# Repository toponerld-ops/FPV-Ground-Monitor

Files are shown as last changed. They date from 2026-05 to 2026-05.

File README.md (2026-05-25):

# FPV Ground Monitor 

A custom-built open-source FPV ground station monitor built on the **Radxa Zero 3W** SBC, featuring a custom uHAT PCB for power management, a RTL8812AU WiFi dongle for receiving **OpenIPC** video streams from drones via **WFB-ng**.

Designed to pair with the **MAR Racing Drone** -- a custom 75mm FPV tiny whoop with a fully custom 8-in-1 AIO flight controller (also Hackclub Fallout funded), this monitor closes the loop on a fully open-source, end-to-end FPV video system.

---

## What is it?

A portable, battery-powered FPV video ground station that:

- Receives HD video from an OpenIPC-based drone over 5.8GHz via WFB-ng
- Displays live feed on a 7" HDMI screen via PixelPilot OS on the Radxa Zero 3W
- Powers everything from a 3S 11.1V li-ion battery via a custom uHAT buck converter PCB
- Features 3x WS2812B RGB LEDs for link/recording/battery status
- Has 3 navigation buttons + 1 power button for PixelPilot UI control
- Has an SSD1306 OLED for IP/battery/link status display
- Exposes a UART debug header for development

---

## Why did I make it?

I'm building the MAR Racing Drone -- a fully custom FPV drone with a custom AIO flight controller and an OpenIPC video system (SSC338Q + IMX415). To test and use the video link, I needed a ground station that:

1. Works with OpenIPC/WFB-ng (no DJI goggles)
2. Is portable and battery powered
3. Is fully open source and hackable
4. Is cheap enough to actually build

Commercial alternatives (DJI Goggles, Walksnail) cost $300-600 and lock you into a proprietary ecosystem. This monitor costs under ₹15,000 (~$180) and works with any OpenIPC drone.

---

## How do you use it?

1. Flash PixelPilot OS onto the 64GB microSD card
2. Plug the RTL8812AU dongle into the USB-A port on the uHAT
3. Connect the 3S battery to the XT30 connector on the uHAT
4. Power on via the power button
5. Connect your 7" HDMI display
6. Power on your OpenIPC drone
7. PixelPilot auto-connects via WFB-ng and displays the video feed

---

## Hardware

### BOM

| Component | Part | Source | Qty | Price (INR) |
|---|---|---|---|---|
| SBC | Radxa Zero 3W 2GB | Hubtronics | 1 | ₹6,900 |
| WiFi Module | RTL8812AU USB dongle | Robokits | 1 | ₹975 |
| Display | Waveshare 7" HDMI Capacitive | Robu | 1 | ₹2,500 |
| Battery | 3S 11.1V 2000mAh Li-ion | Robu | 1 | ₹900 |
| MicroSD | SanDisk 64GB A1 | Robu | 1 | ₹550 |
| uHAT PCB | Custom (this repo) | JLCPCB | 1 | ~₹800 |
| Buck Converter | MP2307DN-LF-Z | LCSC C18921 | 1 | - |
| RGB LEDs | WS2812B-V5 | LCSC C691873 | 3 | - |
| Buttons | TS-1187A-B-A-B | LCSC C318884 | 4 | - |
| OLED | SSD1306 128x64 I2C module | AliExpress | 1 | ₹150 |
| 40-pin Header | IDC-SMD_40P-P2.54 | LCSC C9900016611 | 1 | - |
| USB-A Socket | USB3.0VerticalTypeA | LCSC C9900010398 | 1 | - |
| Battery Connector | KF301-2P | LCSC C9900016950 | 1 | - |

Full BOM with LCSC part numbers in `BOM(1).csv`

---

## PCB -- uHAT

The custom uHAT PCB sits on top of the Radxa Zero 3W's 40-pin GPIO header and provides:

- **Power**: 11.1V 3S battery → MP2307 buck converter → 5V rail for Zero 3W + display
- **USB**: Routes USB 2.0 from GPIO header pins 27/28 to USB-A socket for WiFi dongle
- **Interface**: 4x tactile buttons, 3x WS2812B RGB LEDs, SSD1306 OLED connector
- **Debug**: UART header (TX/RX/GND) for serial debug access
- **Protection**: Polyfuse on battery input, 100nF decoupling on all power rails

### PCB Specs
- Size: 65 x 30mm
- Layers: 2
- Manufacturer: JLCPCB standard

---
### Firmware
The FPV Ground Monitor runs PixelPilot OS on the Radxa Zero 3W SBC. PixelPilot is an open-source ground station OS built specifically for OpenIPC FPV systems using WFB-ng.
No custom firmware is required -- PixelPilot handles video decoding, display output, and WiFi link management out of the box.

Setup Instructions
1. Flash PixelPilot OS

Download the latest PixelPilot OS image for Radxa Zero 3W from:
https://github.com/OpenIPC/PixelPilot/releases
Flash to a 64GB microSD card using Balena Etcher
Insert microSD into the Radxa Zero 3W

2. Hardware Assembly

Plug the RTL8812AU WiFi dongle into the USB-A port on the uHAT
Connect the 3S 11.1V battery to the XT30 connector on the uHAT
Connect the 7" HDMI display via micro HDMI to HDMI cable
Stack the uHAT onto the Radxa Zero 3W 40-pin GPIO header

3. Power On

Press the power button on the uHAT
PixelPilot OS boots automatically
The RTL8812AU driver is included in PixelPilot OS -- no manual setup needed

4. Connecting to Drone

Power on your OpenIPC drone with WFB-ng configured
PixelPilot automatically scans for WFB-ng streams on 5.8GHz
Video feed appears on the HDMI display within 5-10 seconds

WFB-ng Configuration
For the drone side (MAR Racing Drone AIO FC with SSC338Q + IMX415):

WFB-ng frequency: 5745 MHz (default)
TX power: set in /etc/wfb.conf on the drone
Recommended MCS index: 1 (balance of range and bitrate)
Encoding: H.265 for best quality at low bitrate

For full WFB-ng configuration guide:
https://github.com/svpcom/wfb-ng/wiki

GPIO Button and LED Control (Optional)
The uHAT exposes 4 buttons and 3 WS2812B RGB LEDs via the Radxa Zero 3W GPIO. A Python script can be run on boot to handle these.
Dependencies:
pip install RPi.GPIO rpi-ws281x
Button GPIO pins (BCM numbering):

BTN1: GPIO17 (Pin 11)
BTN2: GPIO27 (Pin 13)
BTN3: GPIO22 (Pin 15)
PWR BTN: GPIO23 (Pin 16)

LED data pin:

GPIO_LED1: GPIO24 (Pin 18) -- WS2812B data in

OLED (SSD1306 I2C):

SDA: GPIO2 (Pin 3)
SCL: GPIO3 (Pin 5)

Sample script for LED status and OLED display coming soon.

References

PixelPilot: https://github.com/OpenIPC/PixelPilot

WFB-ng: https://github.com/svpcom/wfb-ng

OpenIPC: https://openipc.org

Radxa Zero 3W: https://radxa.com/products/zeros/zero3w

---

## Zine Page

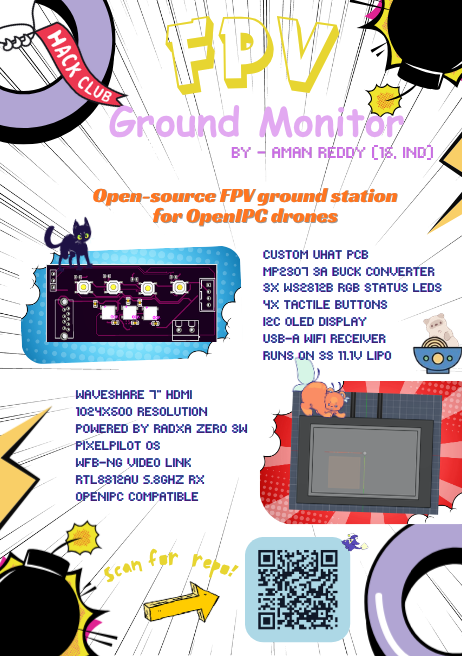
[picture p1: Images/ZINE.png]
Zine Page


---

## Top View

Top View

## Side view

Side View

## Bottom view 

Bottom View

## PCB Top view

PCB Top view

## PCB Bottom view

PCB Bottom view

---

**Made by Aman | Age 16 | Hyderabad, India**

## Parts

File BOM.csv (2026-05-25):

No. | Quantity | Component | Designator | Footprint | LCSC Part | Manufacturer | Price (INR) | Category | Notes | Link
1 | 14 | 100nF Capacitor 0603 | C1-C14 | C0603 | C14663 |  | 2 | PCB Component | Hand Solder | https://www.lcsc.com/product-detail/C14663.html
2 | 1 | 4.7uH Inductor 0603 | L1 | L0603 | C1034 |  | 4 | PCB Component | Hand Solder | https://www.lcsc.com/product-detail/C1034.html
3 | 1 | 100K Resistor 0603 | R1 | R0603 | C25803 |  | 1 | PCB Component | Hand Solder | https://www.lcsc.com/product-detail/C25803.html
4 | 1 | 25.5K Resistor 0603 | R2 | R0603 | C22920 |  | 1 | PCB Component | Hand Solder | https://www.lcsc.com/product-detail/C22920.html
5 | 4 | 10K Resistor 0603 | R3-R6 | R0603 | C25804 |  | 2 | PCB Component | Hand Solder | https://www.lcsc.com/product-detail/C25804.html
6 | 1 | SS34 Schottky Diode | D1 | SOD-123 | C108862 |  | 2 | PCB Component | Hand Solder | https://www.lcsc.com/product-detail/C108862.html
7 | 4 | TS-1187A-B-A-B Tactile Switch | SW1-SW4 | SW-SMD-4P | C318884 | XKB Connection | 2 | PCB Component | Hand Solder | https://www.lcsc.com/product-detail/C318884.html
8 | 1 | MP2307DN-LF-Z Buck Converter | U1 | SOIC-8N-EP | C18921 | MPS | 308 | PCB Component | Reflow Solder | https://www.lcsc.com/product-detail/C18921.html
9 | 3 | WS2812B-V5/W RGB LED | U5-U7 | LED-SMD-5x5 | C2874885 |  | 12 | PCB Component | Reflow Solder | https://www.lcsc.com/product-detail/C2874885.html
10 | 1 | Fuse F1206 | F1 | F1206 | C9900021114 |  | 5 | PCB Component | Hand Solder | https://www.lcsc.com/product-detail/C9900021114.html
11 | 1 | KF301-2P Screw Terminal | P1 | CONN-TH | C9900016950 |  | 5 | PCB Component | Hand Solder | https://www.lcsc.com/product-detail/C9900016950.html
12 | 1 | 40P 2.54mm GPIO Header | U2 | HDR-SMD-40P | C9900016611 |  | 15 | PCB Component | Hand Solder | https://www.lcsc.com/product-detail/C9900016611.html
13 | 1 | USB 3.0 Type-A Vertical Socket | U3 | USB-A-TH | C9900010398 |  | 5 | PCB Component | Hand Solder | https://www.lcsc.com/product-detail/C9900010398.html
14 | 1 | 1X4P Pin Header 2.54mm | U4 | CONN-TH-4P | C9900022166 |  | 3 | PCB Component | Hand Solder | https://www.lcsc.com/product-detail/C9900022166.html
15 | 1 | 1X3P Pin Header 2.54mm | U8 | HDR-TH-3P | C9900016709 |  | 3 | PCB Component | Hand Solder | https://www.lcsc.com/product-detail/C9900016709.html
16 | 1 | PCB Fabrication + Stencil (JLCPCB - 5 boards) |  |  |  | JLCPCB | 2060 | PCB |  | https://jlcpcb.com
17 | 1 | Radxa Zero 3W 2GB SBC |  |  |  | Radxa | 6900 | Electronics |  | https://radxa.com/products/zeros/zero3w
18 | 1 | RTL8812AU USB WiFi Dongle |  |  |  | Generic | 975 | Electronics |  | https://robu.in/product/rtl8812au-600mbps-dual-band-wireless-usb-wifi-adapter/
19 | 1 | Waveshare 7inch HDMI LCD 1024x600 |  |  |  | Waveshare | 2500 | Electronics |  | https://robu.in/product/waveshare-7inch-hdmi-lcd/
20 | 1 | 3S 11.1V 2000mAh Li-ion Battery |  |  |  | Generic | 900 | Electronics |  | https://robu.in/product/11-1v-2000mah-3c-3s1p-li-ion-battery-pack/
21 | 1 | SanDisk 64GB MicroSD A1 |  |  |  | SanDisk | 550 | Electronics |  | https://robu.in/product/sandisk-64gb-ultra-microsdxc-uhs-i-card/
22 | 1 | SSD1306 128x64 OLED Module |  |  |  | Generic | 150 | Electronics |  | https://robu.in/product/0-96-inch-i2c-iic-serial-128x64-oled-lcd-led-display-module/
23 | 1 | Micro HDMI to HDMI Cable |  |  |  | Generic | 200 | Electronics |  | https://robu.in
24 | 1 | YIHUA 926 Soldering Station |  |  |  | YIHUA | 1440 | Tool |  | https://robu.in/product/yihua-926-upgrade-version-soldering-iron-station/
25 | 1 | ELBME G3061 PD65W Hot Plate |  |  |  | ELBME | 4989 | Tool |  | https://www.amazon.in/dp/B0F3TP5X62
26 | 1 | Noise 65W GaN Charger + USB-C Cable |  |  |  | Noise | 2399 | Tool |  | https://www.amazon.in/dp/B0F9F2RCR4
27 | 1 | boAt USB-C to USB-C Cable |  |  |  | boAt | 349 | Tool |  | https://www.amazon.in/dp/B0FMRNR4LY
28 | 1 | SMD Solder Paste (63/37) |  |  |  | Generic | 300 | Tool |  | https://robu.in
TOTAL |  |  |  |  |  |  | 23082

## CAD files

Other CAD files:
CAD/FPV_GROUND_STATION_CAD_CASE (Assembly).step
CAD/FPV_GROUND_STATION_CAD_CASE.step
CAD/FPV_GROUND_STATION_CAD_CASE.f3d

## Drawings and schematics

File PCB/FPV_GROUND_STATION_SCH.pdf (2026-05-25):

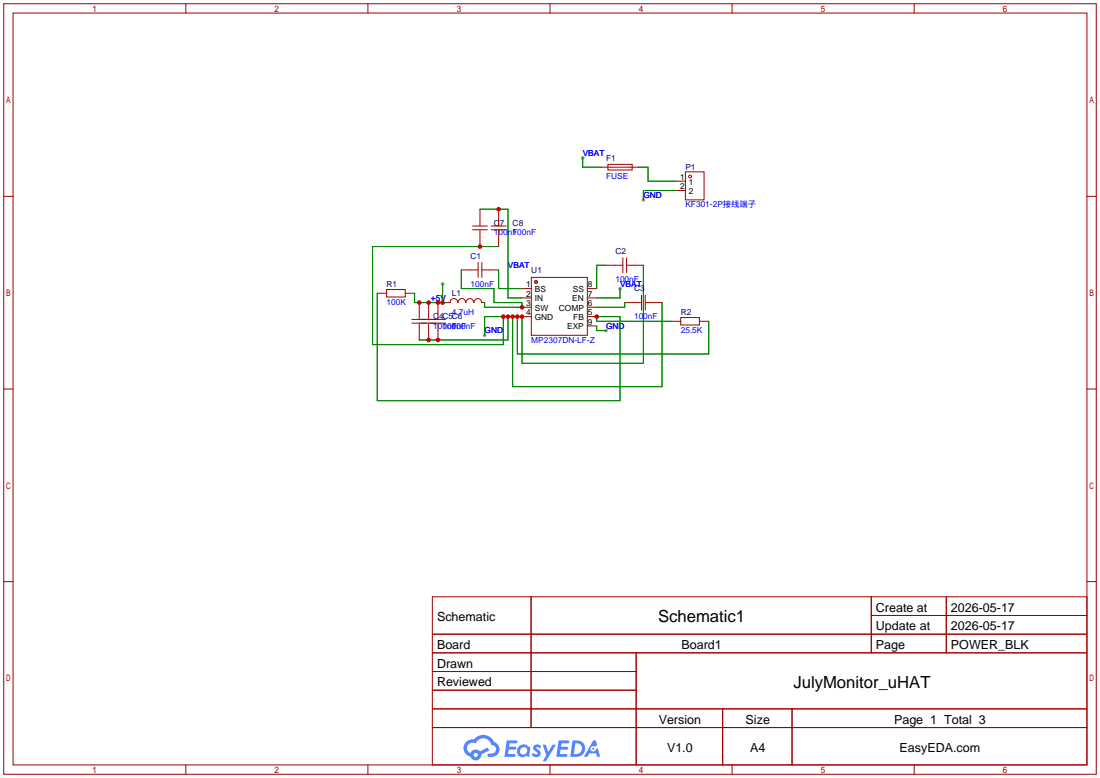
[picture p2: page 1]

Schematic | Schematic1 | Create at | 2026-05-17

Update at | 2026-05-17

Board | Board1 | Page | POWER_BLK
Drawn | | JulyMonitor_uHAT
Reviewed

Version | Size | Page 1 Total 3
V1.0 | A4 | EasyEDA.com

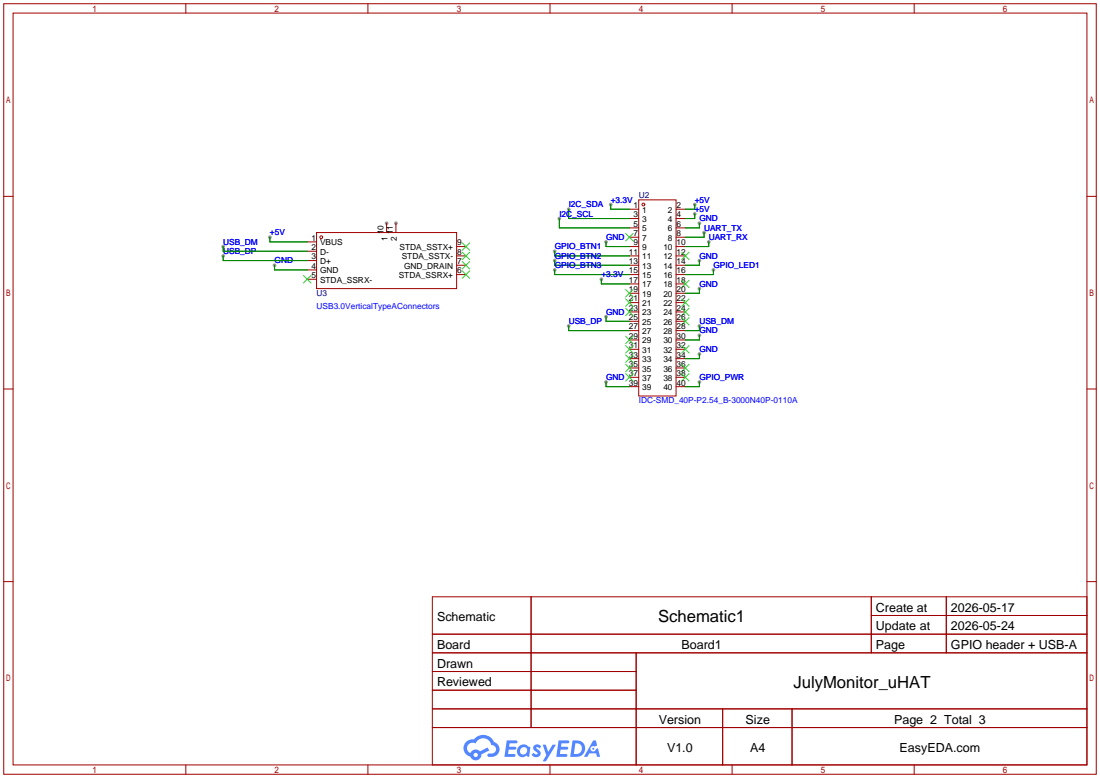
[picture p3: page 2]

Schematic | Schematic1 | Create at | 2026-05-17

Update at | 2026-05-24

Board | Board1 | Page | GPIO header + USB-A
Drawn | | JulyMonitor_uHAT
Reviewed

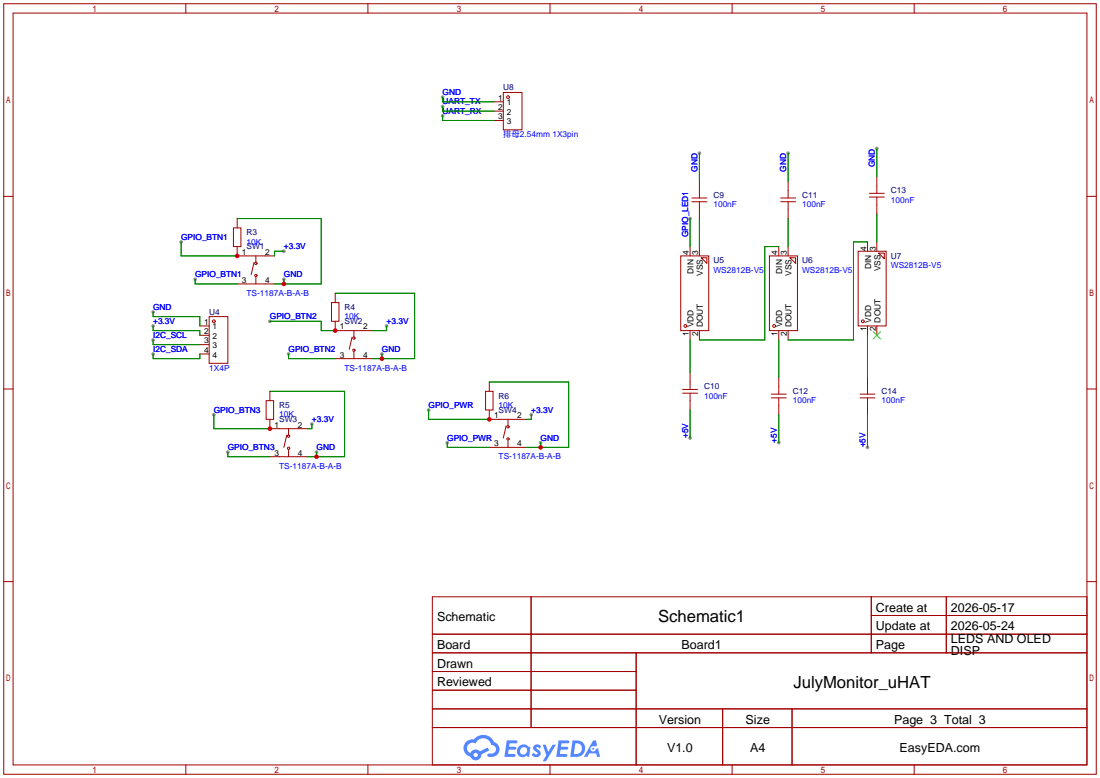
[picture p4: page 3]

Schematic | Schematic1 | Create at | 2026-05-17
Board | Board1 | Page | LEDS AND OLED
Drawn | | JulyMonitor_uHAT
Reviewed

Update at | 2026-05-24

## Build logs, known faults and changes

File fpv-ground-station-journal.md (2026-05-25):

# FPV GROUND STATION — Journal Export

- Exported at: 2026-05-25T13:59:48Z
- Project ID: 3503
- Entries: 17

## Entry 1
- ID: 7588
- Author: toponerld
- Created At: 2026-05-17T11:36:19Z

### Content

Started the uHAT schematic for the July FPV Monitor in EasyEDA Pro. The uHAT sits on top of the Radxa Zero 3W's 40-pin GPIO header and handles all the power management for the monitor.
Today I completed the power input block. The battery connects through a KF301-2P screw terminal, goes through a fuse for protection, and into an MP2307DN buck converter that steps the 11.1V 3S li ion battery down to a clean 5V rail. Added input and output filtering caps, bootstrap cap, soft start cap, freewheeling SS34 Schottky diode, and a resistor divider on the FB pin set for 5V output.
Next up: 40-pin GPIO header for the Radxa Zero 3W and the USB-A socket for the RTL8812AU WiFi dongle.
Screenshot 2026-05-17 165958.png

### Recording Links

- https://public.lapse-hackclub.link/timelapses/X917GN-vhyAR/timelapse-X917GN-vhyAR.mp4

## Entry 2
- ID: 7595
- Author: toponerld
- Created At: 2026-05-17T12:15:31Z

### Content

Added the Radxa Zero 3W 40-pin GPIO header (IDC-SMD_40P-P2.54) and mapped all used pins 5V power input, GND, 3.3V, I2C for OLED, UART for debug, and 6 GPIO pins for buttons and LEDs. Remaining pins got no-connect markers.
Added a USB 3.0 Type-A vertical socket for the RTL8812AU WiFi dongle. Connected VBUS to +5V, GND, and routed D+ and D- to pins 27 and 28 on the GPIO header. SS pins no-connected since Zero 3W GPIO only exposes USB 2.0.
Next: buttons, LEDs and OLED 
Screenshot 2026-05-17 174520.png

### Recording Links

- https://public.lapse-hackclub.link/timelapses/cNxJUGiLqJAZ/timelapse-cNxJUGiLqJAZ.mp4

## Entry 3
- ID: 7601
- Author: toponerld
- Created At: 2026-05-17T12:54:14Z

### Content

Added the interface components on page 3. Placed a 4-pin header for the SSD1306 OLED module connected to I2C (SCL/SDA) with 3.3V and GND.
Added 4 tactile buttons (TS-1187A-B-A-B) -- 3 for UI navigation and 1 dedicated power button. Each has a 10K pulldown resistor to ensure clean LOW reads when unpressed.
For LEDs went with 3x WS2812B-V5 addressable RGB LEDs instead of plain single color -- all controlled from a single GPIO pin via data chaining. Each LED has a dedicated role: link status, recording status, and battery level. Added 100nF decoupling caps on each.
DRC passed with 0 errors on all 3 pages.
Next: PCB layout.
Screenshot 2026-05-17 182300.png

### Recording Links

- https://public.lapse-hackclub.link/timelapses/5m16LrcEGvKj/timelapse-5m16LrcEGvKj.mp4

## Entry 4
- ID: 7637
- Author: toponerld
- Created At: 2026-05-17T16:38:28Z

### Content

Finished the schematic and started tracing the pcb looks like i have a lot to learn in tracing will take help
Screenshot 2026-05-17 220814.png

### Recording Links

- https://public.lapse-hackclub.link/timelapses/uewIPvZDGqOo/timelapse-uewIPvZDGqOo.mp4

## Entry 5
- ID: 8815
- Author: toponerld
- Created At: 2026-05-24T07:38:45Z

### Content

soooooo i forgot to save and i lost my traced pcb so i made it again and have no errors in drc and have a few errors in dfm so have to fix those 
Screenshot 2026-05-24 130830.png

### Recording Links

- https://public.lapse-hackclub.link/timelapses/6hfgF1i-I5Ng/timelapse-6hfgF1i-I5Ng.mp4
- https://public.lapse-hackclub.link/timelapses/8OSZpo_ioEFw/timelapse-8OSZpo_ioEFw.mp4

## Entry 6
- ID: 8825
- Author: toponerld
- Created At: 2026-05-24T09:02:11Z

### Content

okayy so finished everything only silkscreen errors in dfm so the pcb is done!!!! now its time to build it heheheh.
Screenshot 2026-05-24 142334.png

### Recording Links

- https://public.lapse-hackclub.link/timelapses/la_aP5qNe96_/timelapse-la_aP5qNe96_.mp4

## Entry 7
- ID: 8861
- Author: toponerld
- Created At: 2026-05-24T13:12:09Z

### Content

Im making the outer case for the fpv ground station i paused a lot in between cause i was taking measurements from the PCB i made 
Screenshot 2026-05-24 183717.png
Screenshot 2026-05-24 184144.png

### Recording Links

- https://public.lapse-hackclub.link/timelapses/Htptf2LEvjc1/timelapse-Htptf2LEvjc1.mp4

## Entry 8
- ID: 8873
- Author: toponerld
- Created At: 2026-05-24T14:32:58Z

### Content

major changes looks like i messed up the button, led and the connector holes and then i added the step files of the components then assembled them now i have to make the holes for them then it will be done heheh.
Screenshot 2026-05-24 200159.png
Screenshot 2026-05-24 200247.png

### Recording Links

- https://public.lapse-hackclub.link/timelapses/Tq5StU_N6Mgt/timelapse-Tq5StU_N6Mgt.mp4

## Entry 9
- ID: 8889
- Author: toponerld
- Created At: 2026-05-24T15:41:06Z

### Content

uhhhhhhhhhhhh i cant seem to find how to make holes to the case according to the pcb i made on the case!!
Screenshot 2026-05-24 211056.png

### Recording Links

- https://public.lapse-hackclub.link/timelapses/W3pzDga-OvNf/timelapse-W3pzDga-OvNf.mp4

## Entry 10
- ID: 8916
- Author: toponerld
- Created At: 2026-05-24T16:59:24Z

### Content

sooooo i finished the holes for the pcb buttons and ledsss finnally i can sleep i grinded alott today gettin closer to the goal imma give my very best so that i can go to sz!!
Screenshot 2026-05-24 222402.png

### Recording Links

- https://public.lapse-hackclub.link/timelapses/qM8SKp4SDo91/timelapse-qM8SKp4SDo91.mp4

## Entry 11
- ID: 9014
- Author: toponerld
- Created At: 2026-05-25T02:22:44Z

### Content

made the antennas or the case and added support brackets and mounting holes for the radax pi zero w3 
Screenshot 2026-05-25 075218.png

### Recording Links

- https://public.lapse-hackclub.link/timelapses/9Zzg_7UHkDmC/timelapse-9Zzg_7UHkDmC.mp4

## Entry 12
- ID: 9023
- Author: toponerld
- Created At: 2026-05-25T03:32:46Z

### Content

soo i finished everything now making the repo so i made the BOM and uploaded all the files then set up lfs cause the files were too big and made the repo clean. i have to finalize the BOM and submit!!
Screenshot 2026-05-25 083422.png

### Recording Links

- https://public.lapse-hackclub.link/timelapses/kwZ2xxx-BgNz/timelapse-kwZ2xxx-BgNz.mp4

## Entry 13
- ID: 9040
- Author: toponerld
- Created At: 2026-05-25T04:48:32Z

### Content

im havin problems with jlcpcb looks llike sm of my components are out of stock so i got fedup and started making the zine page will complete soon, wish me luck!
Screenshot 2026-05-25 101821.png

### Recording Links

- https://public.lapse-hackclub.link/timelapses/U2qUrNBQRouZ/timelapse-U2qUrNBQRouZ.mp4

## Entry 14
- ID: 9063
- Author: toponerld
- Created At: 2026-05-25T08:35:56Z

### Content

Made the zine pagee put a lot of effort into itt and a bit of advice from krishh!! it looks good hope it will get printed
FPV (1).png

### Recording Links

- https://public.lapse-hackclub.link/timelapses/IqYz93zXrst4/timelapse-IqYz93zXrst4.mp4

## Entry 15
- ID: 9073
- Author: toponerld
- Created At: 2026-05-25T09:42:43Z

### Content

I completed the zine before but missed a couple of things like the name age country a brief discription so ive added those now


### Recording Links

- https://public.lapse-hackclub.link/timelapses/jWElGVDbj_cF/timelapse-jWElGVDbj_cF.mp4

## Entry 16
- ID: 9086
- Author: toponerld
- Created At: 2026-05-25T10:49:25Z

### Content

I removed all the components from the top side of the pcb and place them all on the bottom side to cut costs, it was a lot of workkk
Screenshot 2026-05-25 161907.png

### Recording Links

- https://public.lapse-hackclub.link/timelapses/EmE-8jUR9670/timelapse-EmE-8jUR9670.mp4

## Entry 17
- ID: 9104
- Author: toponerld
- Created At: 2026-05-25T13:02:16Z

### Content

So i found out that unlike BP Fallout allows grants for tools so instead of spending 150$ on a pcba i decided to do sm research on tools. and i also made alot of additions and changes to the github repo
Screenshot 2026-05-25 183156.png
Screenshot 2026-05-25 173958.png

### Recording Links

- https://public.lapse-hackclub.link/timelapses/0TN58jZo2xLi/timelapse-0TN58jZo2xLi.mp4

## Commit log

2026-05-24 Create PCB
2026-05-25 Track STEP files with LFS
2026-05-25 Add CAD STEP files
    [FPV_GROUND_STATION_CAD_CASE (Assembly).step, FPV_GROUND_STATION_CAD_CASE.step]
2026-05-25 Update BOM file name in README
2026-05-25 Rename Screenshot 2026-05-25 193557.png to PCB_BOTTOM
2026-05-25 Rename Screenshot 2026-05-25 193609.png to PCB_TOP
2026-05-26 Rename BOM (1).csv to BOM.csv
    [BOM.csv]
